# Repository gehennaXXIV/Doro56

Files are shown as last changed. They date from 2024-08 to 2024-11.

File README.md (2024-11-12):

# Doro56
***
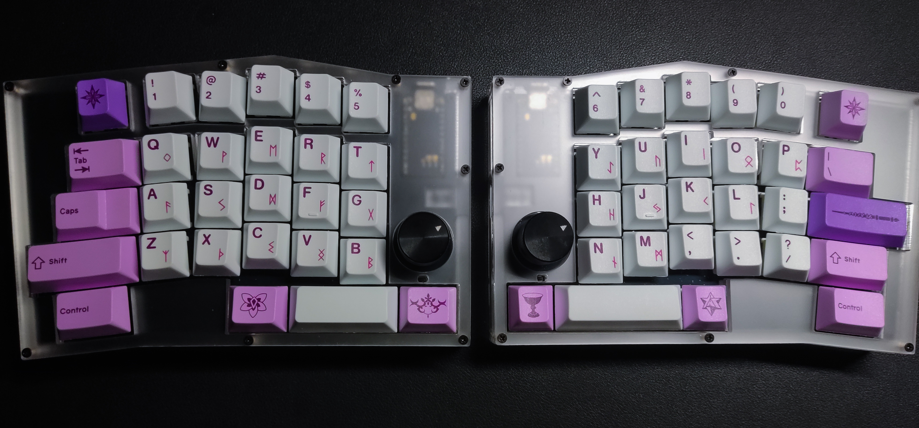
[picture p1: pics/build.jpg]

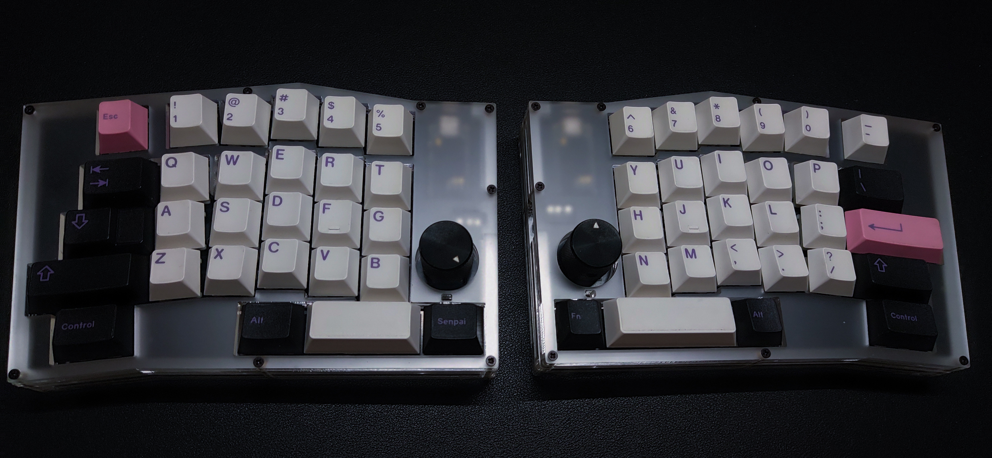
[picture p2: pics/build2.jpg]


A 56-key split keyboard with a reversible PCB that uses normal mods, an exploded number row, a semi-columnar staggered layout, plus support for rotary encoders. Mainly inspired by Alice layouts and split boards like the Lily58 and Corne.

[ZMK config](https://github.com/gehennaXXIV/zmk-config-Doro56)
 - support for https://nickcoutsos.github.io/keymap-editor/ and https://zmk.studio/

QMK config - None yet - RP2040 Pro Micro support soon

***
## Changelog

#### v1.2 - Minor Edit
- **JST PH Footprint**: The footprint has been updated to avoid the need for manually changing plug polarity. Ensure the Red (+) wire matches the plug's positive pin as the 2 outer pins are negative/ground pins. If your plug isn't matching the indicators, just shift the socket one pin sideways. Note: This socket is installed on the bottom of the half you're building.

#### v1.1 - Minor Edit
- **Caps and Enter Footprints**: Changed to a single reversible footprint (previously used two single key footprints rotated).
- **JST PH Footprint**: Adjusted and relocated for increased flexibility.
- **Plate**: Slightly increased the cutout size for the rotary encoder.
- **PCB Cutout**: Modified to [remove blank space](https://github.com/gehennaXXIV/Doro56/blob/main/pics/v1.1.png) between Control and Alt keys, allowing space for a 402030 battery without increasing the case height clearance.

***
## Build Guide
Quick overview:
* [Solder the MCU](https://raw.githubusercontent.com/gehennaXXIV/Doro56/main/pics/mcu.jpg) with the components facing down, and the TRRS jack on top of the half you are building. For MCU socketing, the footprint was modified to allow [sockets with thick pins to work](https://down-ph.img.susercontent.com/file/sg-11134201-7qvco-ley7fi4ef44v33). You can use milmax pins, or, what I use, harvested gold pins from a 5-pin RGB header (also cheaper). [Sample 2](https://raw.githubusercontent.com/gehennaXXIV/Doro56/main/pics/sockets.jpg)
* Bridge the [jumpers](https://raw.githubusercontent.com/gehennaXXIV/Doro56/main/pics/bridge.jpg) on the MCU from underneath, and add other components such as diodes, MX sockets, and the power switch.

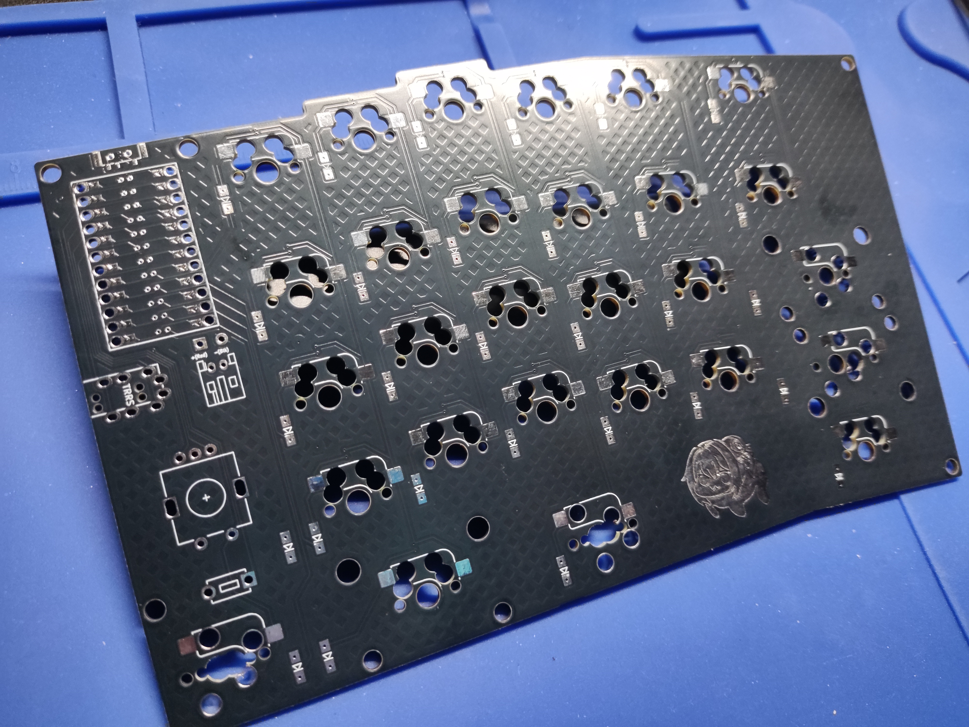
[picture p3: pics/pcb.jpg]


***
## PARTS
| **COMPONENTS** |  Qty  |  Remarks |
| :--- | :---: | :---  |
| Diodes 1N4148W (SMD) |  58 | SOD-123  |
| MX Switch Sockets |  56 | |
| 2U PCB-Mount Stabilizers |  04 | |
| Power Switch |  02 | MSK12C02 |
| Reset Switch |  02 | MJTP1250 |
| JST 2 PH Right Angle Jack |  02 | |
| TRRS Jack |  02 |  MJ-4PP-9 or PJ320A |
| Rotary Encoder |  02 | EC11 - acrylic case has enough clearance for 22mm knobs |

***
| **MCU** |  Qty  |  Remarks |
| :--- | :---: | :---  |
| Low Profile MCU sockets |  04 |  The MCU socket footprint was modified to allow [sockets with thick pins to work](https://down-ph.img.susercontent.com/file/sg-11134201-7qvco-ley7fi4ef44v33). This will make the build cheaper compared to buying Millmax sockets. |
| Mill Max Pins |  48 |  Mouser 3320-0-00-15-00-00-03-0, or a cheaper option: harvested gold pins from a 5-pin RGB header (just snip off the plastic parts) |
| Nice Nanos |  02 |  or NRF52840 clones |
| Li-Po Battery |  02 |  **Take note of the polarity before plugging the battery in.** [Here's a tutorial on how to change the polarity.](https://www.youtube.com/watch?v=za-azgbZor8) |

***
| **CASE** |  Qty  |  Remarks |
| :--- | :---: | :---  |
| [Acrylic Case](/Case/acrylic) |  01 | Maybe a 3DP one soon, but I'm very content with the acrylic case. Let me know if you create one! |
| M2 6mm Wafer Head Screws |  20 | Plate screws |
| M2 10mm Round Standoff Spacer |  10 | Plate standoffs, add +2mm if you need bottom clearance (see case readme) |
| M2 8mm Wafer Head Screws |  32 | Case screws |
| M2 13mm Round Standoff Spacer |  16 | Case standoffs, add +2mm if you need bottom clearance (see case readme) ; can also be -1mm if it's protruding the middle layer |
| Rubber Feet |  08 | Currently, the keyboard lays flat. I’ve yet to design a base layer for angled feet |

***
## FOOTPRINTS USED
* https://github.com/ebastler/marbastlib
* https://github.com/joe-scotto/scottokeebs
* https://github.com/GEIGEIGEIST/KLOR
* https://github.com/50an6xy06r6n/keyboard_reversible.pretty

***
## DISCLAIMER
Please note that while this keyboard is provided as open-source, I am not liable for any issues, malfunctions, or other problems that may arise from its use. The keyboard is provided "as-is," and I make no warranties or guarantees regarding its performance or functionality. Use at your own risk.

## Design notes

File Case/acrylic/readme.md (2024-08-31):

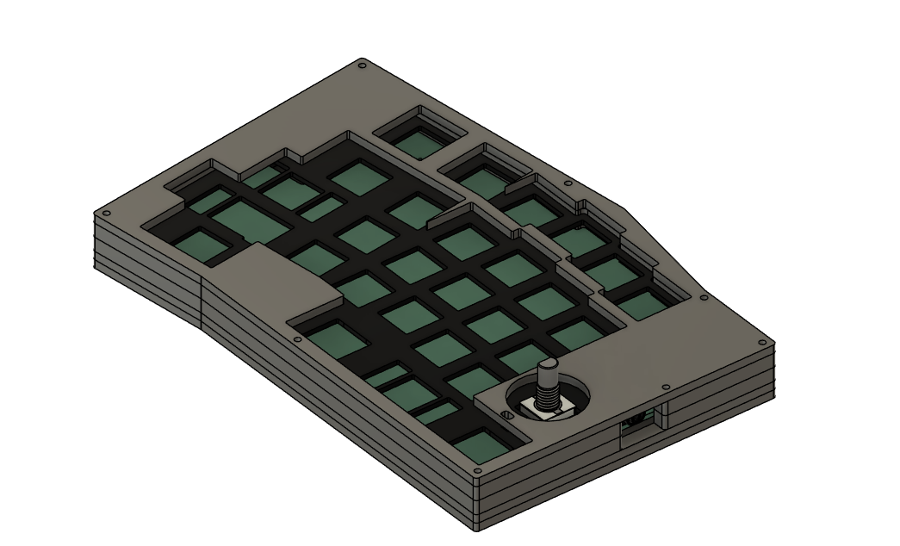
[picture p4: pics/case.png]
Case Image


**Dimensions:**  
- Width: 379.09mm  
- Height: 126.74mm (both sides)

The bottom layer can be either 3mm or 5mm(see 2a) thick, depending on the bottom clearance you need. This clearance is mainly for batteries, so don't forget to add +2mm to both the case and plate brass standoffs as well.

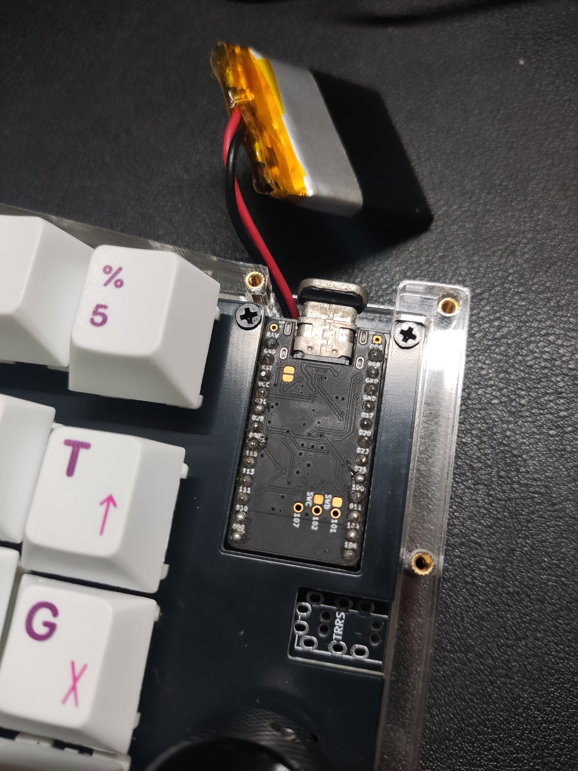
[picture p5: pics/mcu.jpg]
MCU Image


**Bottom Layer (2a):**  
Additional layer if you need bottom clearance, has cutout in the USB section (for power switch clearance)

**Top Layer (4a):**  
If your MCU is taller than the plate, use 1x of this and 1x of the 4 top layer instead. However, I recommend using millmax pins and trimming the excess so they stay flush with the top of the plate. (In my case, I used harvested RGB header pins since they are cheaper.)

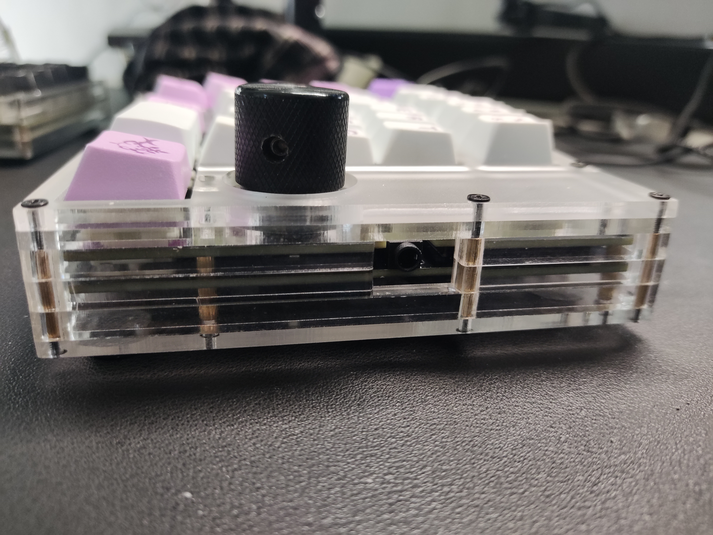
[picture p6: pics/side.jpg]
TRRS Sockets


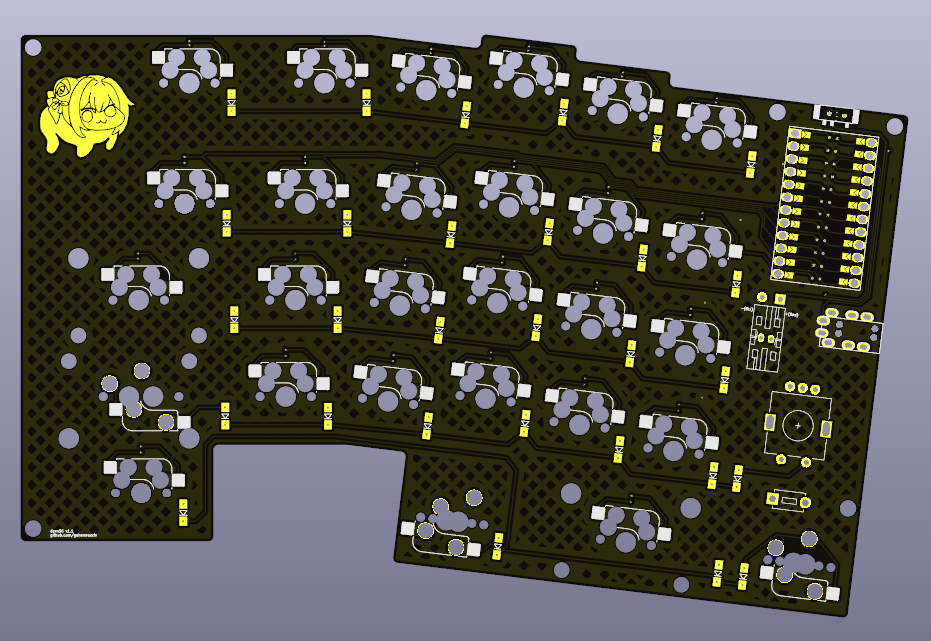
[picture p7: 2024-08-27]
pics/v1.1.png

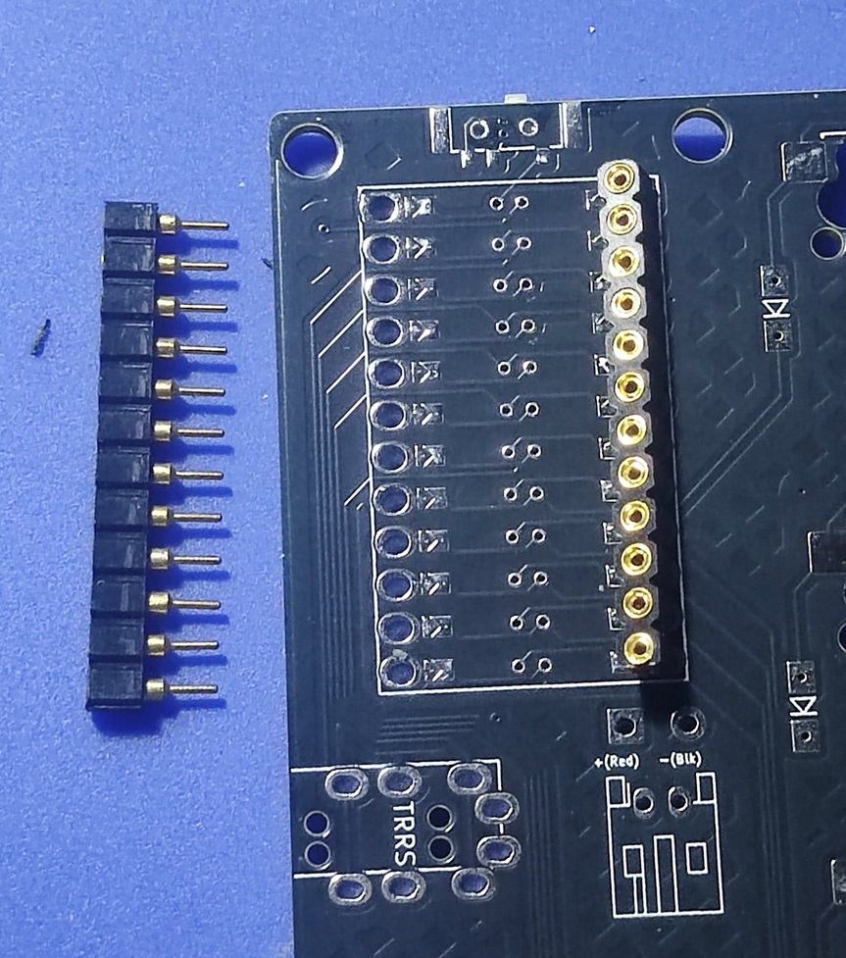
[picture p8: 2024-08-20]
pics/sockets.jpg

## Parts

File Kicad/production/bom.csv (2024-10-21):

Designator | Footprint | Quantity | Value | LCSC Part #
BT1 | JST_PH_2P_Reversible | 1 | Battery_Cell
BT2 | custombatteryconnector_small | 1 | Battery_Cell
D1, D10, D11, D12, D13, D14, D15, D16, D17, D18, D19, D2, D21, D22, D23, D24, D25, D26, D27, D28, D29, D3, D32, D4, D5, D6, D7, D8, D9 | Diode_SOD123 | 29 | D
J1 | MJ-4PP-9 | 1 | MJ-4PP-9
RST1 | Button_MJTP1243 | 1 | SW_Push_45deg
S13, S19, S29 | STAB_MX_2.25u | 3 | MX_stab
SW1, SW10, SW11, SW12, SW13, SW14, SW15, SW16, SW17, SW18, SW2, SW21, SW22, SW23, SW24, SW25, SW3, SW4, SW5, SW6, SW8, SW9 | MX Rev 1U | 22 | SW_Push_45deg
SW19 | MX 2.25U | 1 | SW_Push_45deg
SW20 | MX 1.75U | 1 | SW_Push_45deg
SW26, SW7 | MX Rev 1.5U | 2 | SW_Push_45deg
SW27, SW30 | MX 1.25U | 2 | SW_Push_45deg
SW28, SW31 | MX 1U | 2 | SW_Push_45deg
SW29 | MX Rev 2.25U | 1 | SW_Push_45deg
SW33 | RotaryEncoder_Alps_EC11E-Switch_Vertical_H20mm-keebio_modified | 1 | RotaryEncoder_Switch
SW34 | MSK12C02_reversible | 1 | SW_SPDT

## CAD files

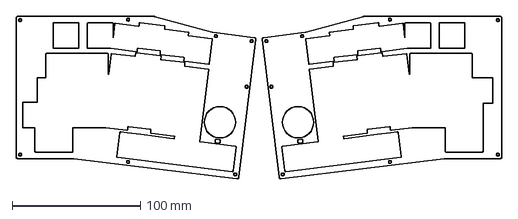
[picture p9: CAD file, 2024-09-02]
Case/acrylic/4 top - 3mm - 2pc.dxf
379.1 x 126.8 mm

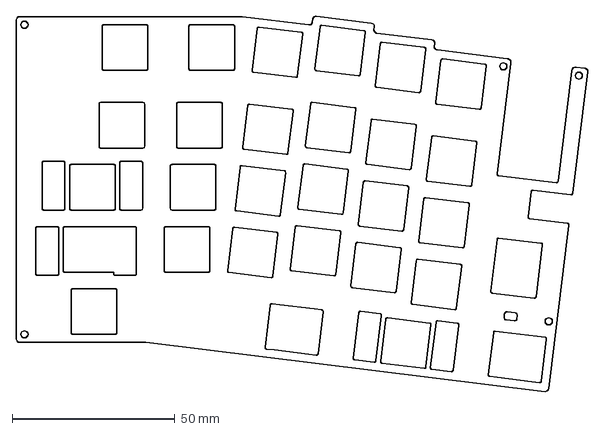
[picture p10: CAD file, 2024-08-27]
Kicad/Doro56-Plate/plate.dxf
175.4 x 115.2 mm

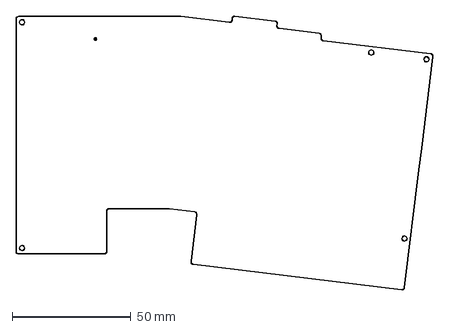
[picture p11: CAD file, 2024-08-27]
Kicad/pcb cutout.dxf
175.4 x 115.2 mm

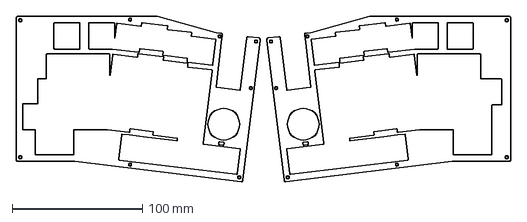
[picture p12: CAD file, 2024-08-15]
Case/acrylic/4a top - 3mm - 1pc.dxf
379.1 x 126.8 mm

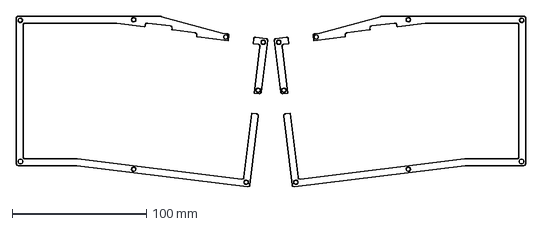
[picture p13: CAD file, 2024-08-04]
Case/acrylic/3a middle - 5mm - 2pcs.dxf
379.1 x 126.8 mm

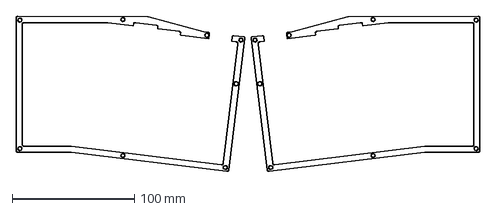
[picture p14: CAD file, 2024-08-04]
Case/acrylic/2a bottom - 2mm - 1pc.dxf
379.1 x 126.8 mm

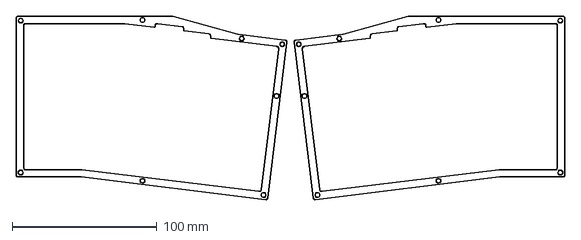
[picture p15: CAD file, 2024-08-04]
Case/acrylic/2 bottom - 3mm - 1pc.dxf
379.1 x 126.8 mm

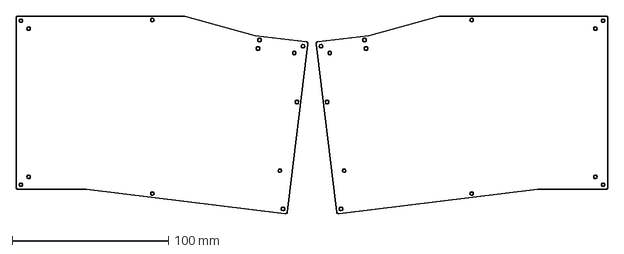
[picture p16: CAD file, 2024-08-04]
Case/acrylic/1 base - 3mm - 1pc.dxf
379.1 x 126.8 mm

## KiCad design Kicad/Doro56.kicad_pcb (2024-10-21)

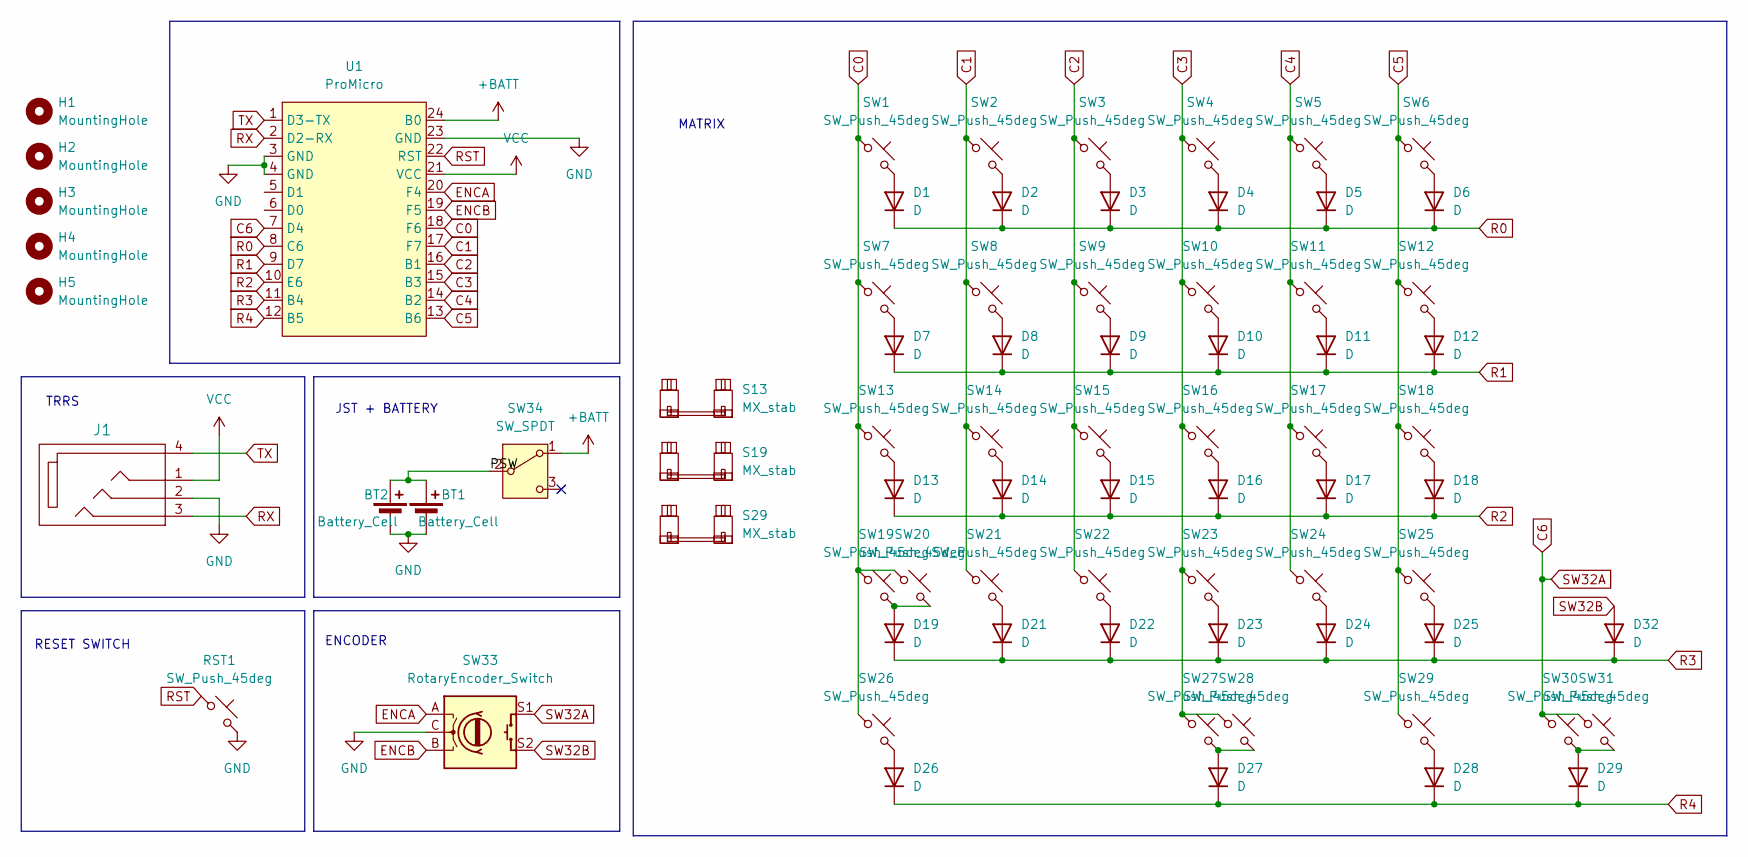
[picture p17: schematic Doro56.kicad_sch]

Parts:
BT1: Battery_Cell; JST_PH_2P_Reversible
BT2: Battery_Cell; custombatteryconnector_small
D1, D2, D3, D4, D5, D6, D7, D8, D9, D10, D11, D12, D13, D14, D15, D16, D17, D18, D19, D21, D22, D23, D24, D25, D26, D27, D28, D29, D32: D; Diode_SOD123
H1, H2, H3, H4, H5: MountingHole; MountingHole_3.2mm_M3
J1: MJ-4PP-9
RST1: SW_Push_45deg; Button_MJTP1243
S13, S19, S29: MX_stab; STAB_MX_2.25u
SW1, SW2, SW3, SW4, SW5, SW6, SW8, SW9, SW10, SW11, SW12, SW13, SW14, SW15, SW16, SW17, SW18, SW21, SW22, SW23, SW24, SW25: SW_Push_45deg; MX Rev 1U
SW7, SW26: SW_Push_45deg; MX Rev 1.5U
SW19: SW_Push_45deg; MX 2.25U
SW20: SW_Push_45deg; MX 1.75U
SW27, SW30: SW_Push_45deg; MX 1.25U
SW28, SW31: SW_Push_45deg; MX 1U
SW29: SW_Push_45deg; MX Rev 2.25U
SW33: RotaryEncoder_Switch; RotaryEncoder_Alps_EC11E-Switch_Vertical_H20mm-keebio_modif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
SW34: SW_SPDT; MSK12C02_reversible
U1: ProMicro; ProMicro_facedown_bigger_holes

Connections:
+BATT: SW34.1 (A), U1.24 (B0)
/PSW: BT1.1 (+), BT2.1 (+), SW34.2 (B)
C0: SW1.1, SW7.1, SW13.1, SW19.1, SW20.1, SW26.1, U1.18 (F6)
C1: SW2.1, SW8.1, SW14.1, SW21.1, U1.17 (F7)
C2: SW3.1, SW9.1, SW15.1, SW22.1, U1.16 (B1)
C3: SW4.1, SW10.1, SW16.1, SW23.1, SW27.1, SW28.1, U1.15 (B3)
C4: SW5.1, SW11.1, SW17.1, SW24.1, U1.14 (B2)
C5: SW6.1, SW12.1, SW18.1, SW25.1, SW29.1, U1.13 (B6)
C6: SW30.1, SW31.1, SW33.S1, U1.7 (D4)
ENCA: SW33.A, U1.20 (F4)
ENCB: SW33.B, U1.19 (F5)
GND: BT1.2 (-), BT2.2 (-), J1.2, RST1.2, SW33.C, U1.3 (GND), U1.4 (GND), U1.23 (GND)
unnamed: D1.2 (A), SW1.2
unnamed: D2.2 (A), SW2.2
unnamed: D3.2 (A), SW3.2
unnamed: D4.2 (A), SW4.2
unnamed: D5.2 (A), SW5.2
unnamed: D6.2 (A), SW6.2
unnamed: D7.2 (A), SW7.2
unnamed: D8.2 (A), SW8.2
unnamed: D9.2 (A), SW9.2
unnamed: D10.2 (A), SW10.2
unnamed: D11.2 (A), SW11.2
unnamed: D12.2 (A), SW12.2
unnamed: D13.2 (A), SW13.2
unnamed: D14.2 (A), SW14.2
unnamed: D15.2 (A), SW15.2
unnamed: D16.2 (A), SW16.2
unnamed: D17.2 (A), SW17.2
unnamed: D18.2 (A), SW18.2
unnamed: D19.2 (A), SW19.2, SW20.2
unnamed: D21.2 (A), SW21.2
unnamed: D22.2 (A), SW22.2
unnamed: D23.2 (A), SW23.2
unnamed: D24.2 (A), SW24.2
unnamed: D25.2 (A), SW25.2
unnamed: D26.2 (A), SW26.2
unnamed: D27.2 (A), SW27.2, SW28.2
unnamed: D28.2 (A), SW29.2
unnamed: D29.2 (A), SW30.2, SW31.2
R0: D1.1 (K), D2.1 (K), D3.1 (K), D4.1 (K), D5.1 (K), D6.1 (K), U1.8 (C6)
R1: D7.1 (K), D8.1 (K), D9.1 (K), D10.1 (K), D11.1 (K), D12.1 (K), U1.9 (D7)
R2: D13.1 (K), D14.1 (K), D15.1 (K), D16.1 (K), D17.1 (K), D18.1 (K), U1.10 (E6)
R3: D19.1 (K), D21.1 (K), D22.1 (K), D23.1 (K), D24.1 (K), D25.1 (K), D32.1 (K), U1.11 (B4)
R4: D26.1 (K), D27.1 (K), D28.1 (K), D29.1 (K), U1.12 (B5)
RST: RST1.1, U1.22 (RST)
RX: J1.3, U1.2 (D2-RX)
SW32B: D32.2 (A), SW33.S2
TX: J1.4, U1.1 (D3-TX)
VCC: J1.1, U1.21 (VCC)

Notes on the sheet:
TRRS
RESET SWITCH
JST + BATTERY
MATRIX
ENCODER

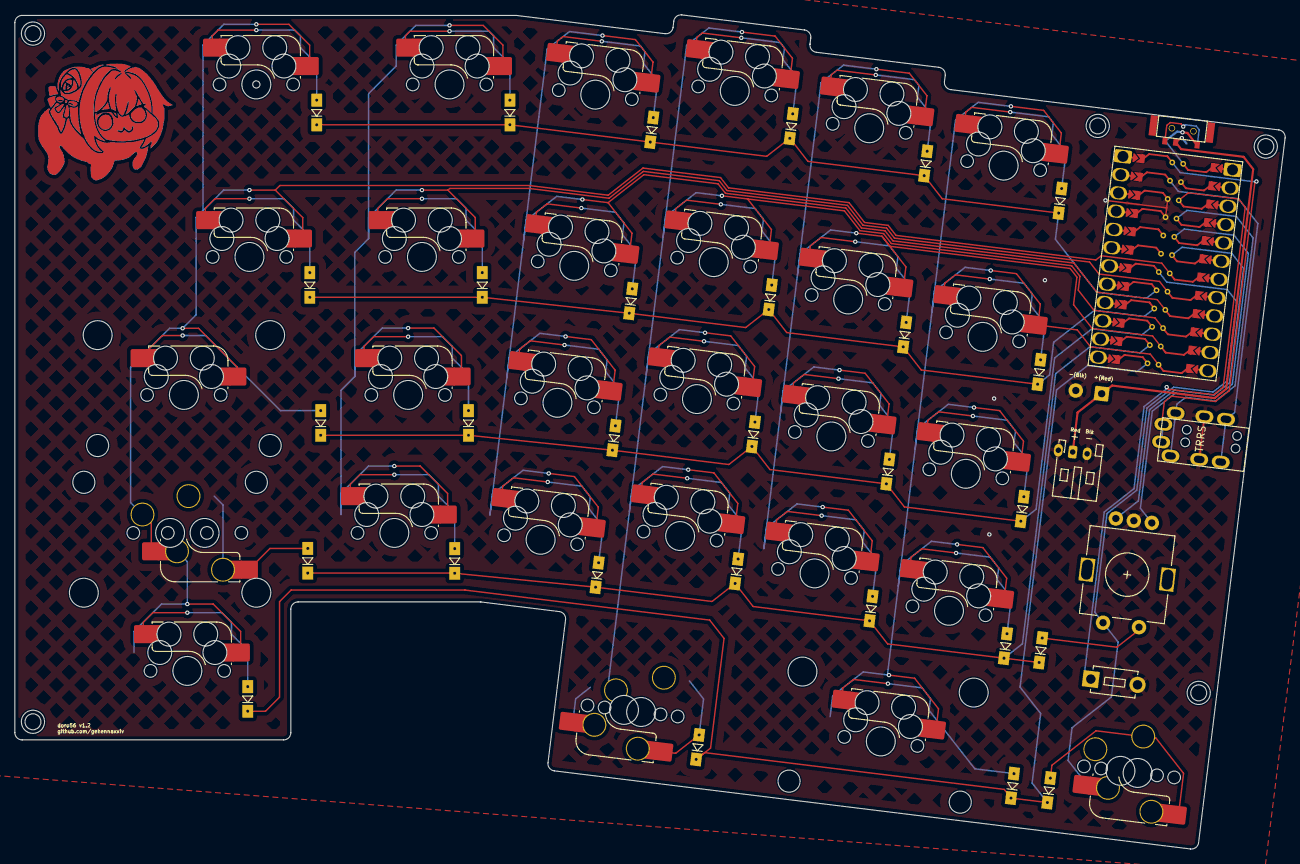
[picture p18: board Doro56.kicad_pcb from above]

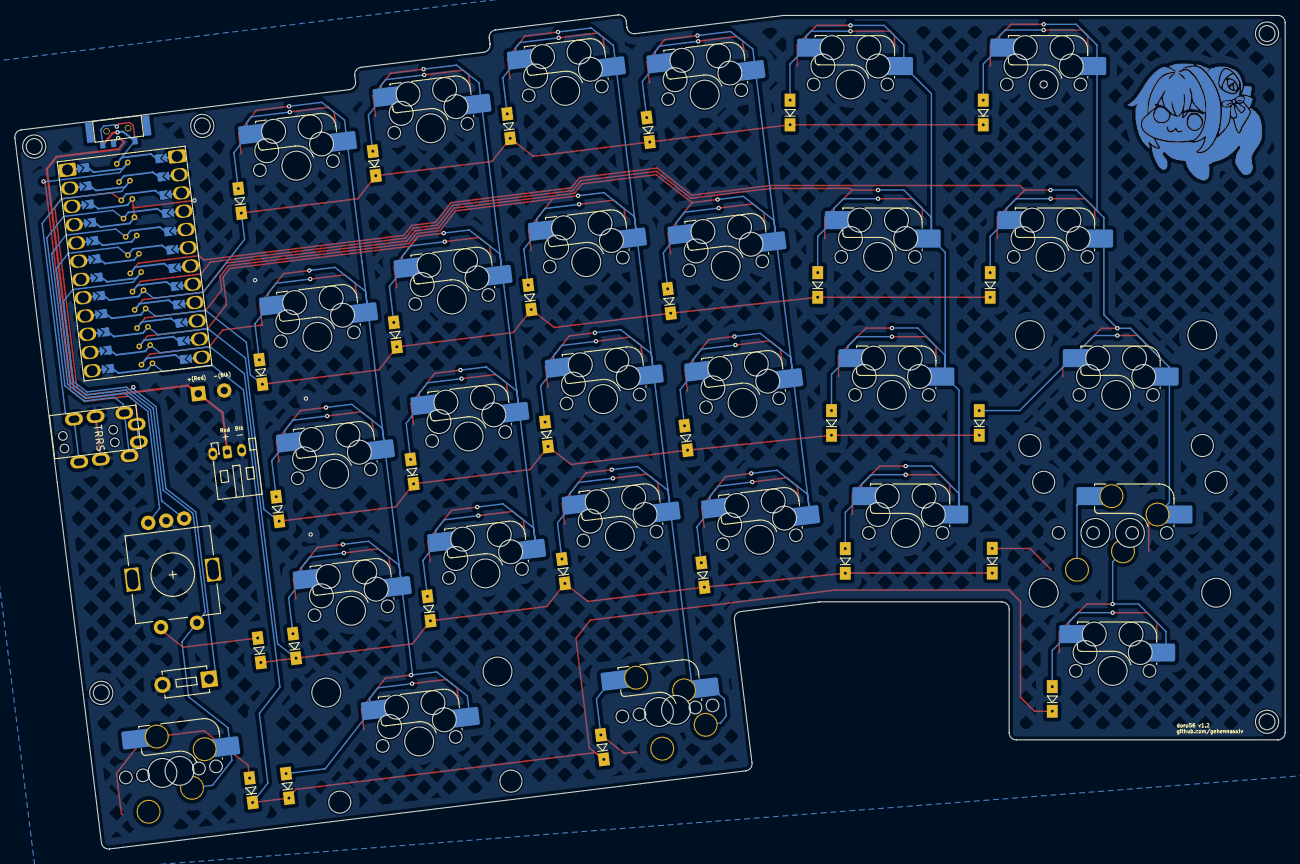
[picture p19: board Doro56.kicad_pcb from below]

Board: 2 copper layers, 175.4 x 115.2 mm, 75 parts (6 on the bottom side), 50 nets.

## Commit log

2024-08-15 blocker fix
    [4 top - 3mm - 2pc.dxf, 4a top - 3mm - 1pc.dxf, Base - 3mm - 2pcs.dxf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]
2024-08-18 pcb pic
2024-08-27 v1.1
    v1.1 - Minor Edit
    Caps and Enter Footprints: Changed to a reversible footprint (previously used two single key footprints rotated).
    JST PH Footprint: Adjusted and relocated for increased flexibility.
    PCB Cutout: Modified to remove blank space between Control and Alt keys, allowing space for a 402030 battery without increasing the case height clearance.
    Plate: Slightly increased the cutout size for the rotary encoder.
    [Base - 3mm - 2pcs.dxf, Doro56-Plate.kicad_pcb, Doro56.kicad_pcb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]
2024-08-31 yeet lego case
    [Doro56.kicad_sch, base 2mm.dxf, mid 5mm.dxf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]
2024-08-31 docs update
    [2 bottom - 3mm - 1pc.dxf, 2a bottom - 2mm - 1pc.dxf]
